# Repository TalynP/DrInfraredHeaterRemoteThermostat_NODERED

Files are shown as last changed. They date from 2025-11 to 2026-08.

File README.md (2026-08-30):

# Dr Infrared Heater Remote Thermostat

Controls a Dr Infrared Heater ([DR-996](https://drheaterusa.com/products/dr966-240-volt-hardwired-shop-garage-commercial-heater-3000-watt-6000-watt)) over a local Wi-Fi network.

This project uses a [Raspberry Pi Software Zero 2W](https://www.raspberrypi.com/products/raspberry-pi-zero-2-w/) with Raspbian GNU/Linux 12 (bookworm) with [Node-RED](https://nodered.org/) to build the logic of the thermostat.  
  
## User Pages  
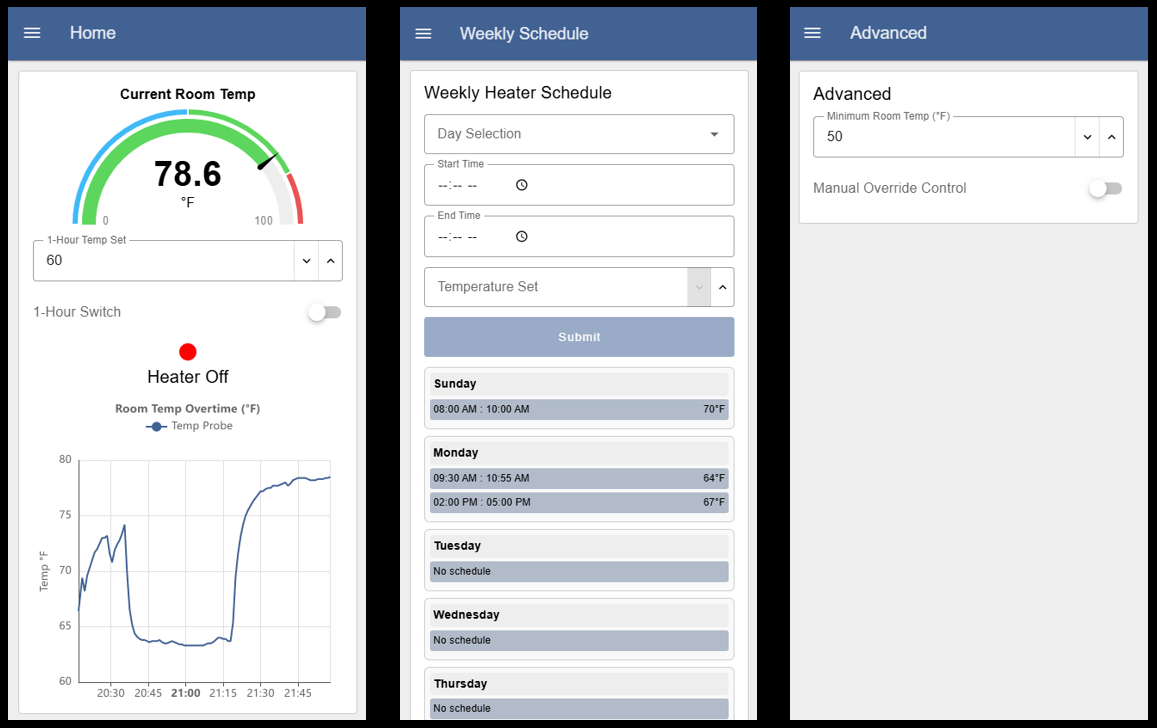
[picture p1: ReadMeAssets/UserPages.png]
Common User Pages


## Navigation
1. [Software Setup](#software-setup)
   - a. [Raspberry Pi Software Install](#raspberry-pi)
   - b. [Node-Red Install](#node-red)
   - c. [nginx and Remote Access](#nginx-and-remote-access)
   - d. [Updating](#applying-updates)
2. [Hardware](#hardware)
   - a. [BOM](#bill-of-materials-bom)
   - b. [Mounting Components](#mounting-components)
   - c. [Wiring](#wiring)
   - d. [Heater Control Panel Setup](#heater-control-panel-setup)
   - e. [Printed Circuit Board (PCB) Design](#printed-circuit-board-pcb-design)
3. [Authors Note and Future Features](#authors-note-and-future-features)
    - a. [Future Features](#future-features)

# Software Setup
## Raspberry Pi Software
Install the Raspberry Pi Software OS on to a micro SD card using the [Raspberry Pi Software Imager](https://www.raspberrypi.com/software/) software.
1. SSH into your Raspberry Pi Software
2. Update and Upgrade OS
```bash
sudo apt update && sudo apt upgrade -y
```  
3. Install [Node-RED](https://nodered.org/docs/getting-started/raspberrypi)  
```bash
bash <(curl -sL https://github.com/node-red/linux-installers/releases/latest/download/update-nodejs-and-nodered-deb)
```  
4. When it asks "Would you like to install the Pi Software-specific nodes?" select yes
5. Enable Node-RED service to run on boot  
```bash
sudo systemctl enable nodered.service
```  
6. Start Node-RED  
```bash
node-red-start
```  
7. Once you see "Started flows" type Ctrl+C
8. Enable the 1-wire interface
```bash
sudo raspi-config
```  
9. Navigate to Interface Options -> 1-Wire then select yes to enable
10. Select finish and reboot the system

## Node-RED
### RPi.GPIO Library Install
Depending on your Raspberry Pi Software OS version you may need to install/update the [RPi.GPIO](https://pypi.org/project/RPi.GPIO/) library. Command to install:
```bash
sudo apt install python3-rpi.gpio
```

Reboot your system to refresh everything once installed:
```bash
sudo reboot
```

### Access and Flows
1. Find the IP address or hostname
```bash
hostname && hostname -I
```  
2. Enter IP address or hostname at port 1880 (default Node-RED port) into a web browser  
```bash
http://<your IP or hostname>:1880
```  
3. Login to the Node-RED website  
4. Install [npm](https://www.npmjs.com/) packages from the manage pallet. Install the following:  
[flowfuse node-red-dashboard](https://flows.nodered.org/node/@flowfuse/node-red-dashboard) and [node-red-contrib-sensor-ds18b20](https://flows.nodered.org/node/node-red-contrib-sensor-ds18b20)  
5. Import the [Flows.json](./Flows.json) file ([Node_RED importing guide](https://nodered.org/docs/user-guide/editor/workspace/import-export))  
6. Deploy the new flows  
7. Enter the following in to a web browser to access the user interface
```
http://<your IP or hostname>:1880/dashboard/
```
1. The Advanced page is hidden by default from the navigation bar to access this page go to
```
http://<your IP or hostname>:1880/dashboard/advanced
```

### Flow Files
The Node-RED flows maintain two files the HeaterSchedule.json and HeaterState.log. The HeaterSchedule.json holds the time periods for the heater to maintain a temperature. Then the HeaterState.log writes when the heater turns on and off and logs the source that caused the heater to change state.  
  
An [example heater schedule](./ReadMeAssets/ExampleHeaterSchedule.json) is located in the ReadMeAssets and is described below:  
Sunday - The system will hold 70°F from 8am to 10am  
Monday - The system will hold 65°F from 9am to 11am and will hold 77°F from 2pm to 3pm  
Tuesday, Wednesday, Thursday, Friday, Saturday - No time periods

### Flow Details
For more information on how the Node-RED flows work reference [Node-REDFlowsExplained](./ReadMeAssets/Node-REDFlowsExplained.pdf) located in the ReadMeAssets.

## nginx and Remote Access
### nginx Reverse Proxy (Optional)
[nginx](https://nginx.org/) is used as a simple reverse proxy to allow a hostname such as `http://<your IP or hostname>.local` to show the Node-RED user interface (ui) dashboard website which defaults to `http://<your IP or hostname>.local:1880/dashboard/` and makes the user experience seamless. Below are the steps of how to setup nginx.  
1. Install nginx
```bash
sudo apt update
sudo apt install nginx -y
```
2. Create Node-RED site
```bash
sudo nano /etc/nginx/sites-available/nodered
```
3. Paste the contents below and change __XXXXX__ to your own hostname
```
server {
    listen 80;
    server_name XXXXX.local;

    # Redirect root to /dashboard
    location = / {
        return 301 /dashboard;
    }

    # Proxy /dashboard to Node-RED
    location /dashboard/ {
        proxy_pass http://127.0.0.1:1880/dashboard/;
        proxy_http_version 1.1;
        proxy_set_header Upgrade $http_upgrade;
        proxy_set_header Connection "upgrade";
        proxy_set_header Host $host;
        proxy_set_header X-Real-IP $remote_addr;
        proxy_set_header X-Forwarded-For $proxy_add_x_forwarded_for;
        proxy_set_header X-Forwarded-Proto $scheme;
    }
}
```
4. Once pasted and hostname added type ctrl+O then enter to save the file
5. Once saved exit by typing ctrl+X
6. Point to Node-RED site by linking
```bash
sudo ln -s /etc/nginx/sites-available/nodered /etc/nginx/sites-enabled/
```
7. Remove default nginx site from sites enabled folder (optional but recommended)
```bash
sudo rm /etc/nginx/sites-enabled/default
```
8. Test and reload nginx
```bash
sudo nginx -t
sudo systemctl reload nginx
```
9. Navigate to your `http://XXXXX.local` (server name you put in at step 3)
  
Note - nginx steps assisted in creation with OpenAI ChatGPT.

### Remote Access to the Raspberry Pi Software (Optional)
A native feature for Raspberry Pi Software's is their [Raspberry Pi Software Connect](https://www.raspberrypi.com/software/connect/) software that allows secure remote access to your Raspberry Pi Software. Below I have steps to get this working using a headless (no desktop) Raspberry Pi Software but is best to reference the official Raspberry Pi Software Connect [documentation](https://www.raspberrypi.com/documentation/services/connect.html).  

1. Install Raspberry Pi Software Connect
```bash
sudo apt install rpi-connect-lite
```
2. Turn on
```bash
rpi-connect on
```
3. Enable user lingering to automatically re-login after reboot
```bash
loginctl enable-linger
```
4. Generate hyperlink to login to Raspberry Pi Software Connect and add your Pi Software
```bash
rpi-connect signin
```
5. Use the Raspberry Pi Software Connect website to remotely connect to your Pi Software

## Applying Updates
<details>
<summary>Click to Expand</summary>

1. Acquire the latest version released of [Flows.json](./Flows.json).
2. Open your Node-Red editor.
3. Delete every existing flow (tab workspace).
4. Find the three bars in the top right and select [import](https://nodered.org/docs/user-guide/editor/workspace/import-export).
5. Select "select a file to import" and import the Flows.json file.
6. Select import to "current flow".
7. Select the red "Import" button in the bottom right.
8. If a window appears stating "Some of the nodes you are importing already exist in your workspace." select "View nodes...".
9. Under the "Configuration nodes" section select every nodes checkbox and its replace checkbox to replace all current configuration node with the new updated version.
</details>
<br>

# Hardware
## Bill of Materials (BOM)
A [bill of materials](./ReadMeAssets/DrInfraredHeaterRemoteThermostat_BOM.xlsx) has been provided and is located in the ReadMeAssets folder.

## Mounting Components
### Mounting to the Heater
The Raspberry Pi Software Zero 2W, 5v power supply and relays are mounted to the heater back mount plate then that is attached to the back of the Dr Infrared heater by two short self tapping screws. This mount was 3D printed with PETG (Polyethylene Terephthalate Glycol) the [HeaterBackMountPlate.stl](./ReadMeAssets/HeaterBackMountPlate.stl) file is located in the ReadMeAssets folder.  
  
Components mounted to heater back mount plate  
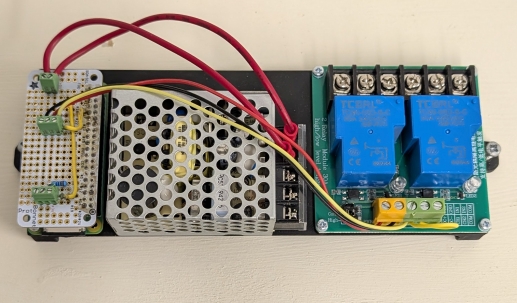
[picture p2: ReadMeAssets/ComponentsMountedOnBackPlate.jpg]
Components mounted on back plate
  

Components and back mount plate mounted to the backside of the DR-996 heater
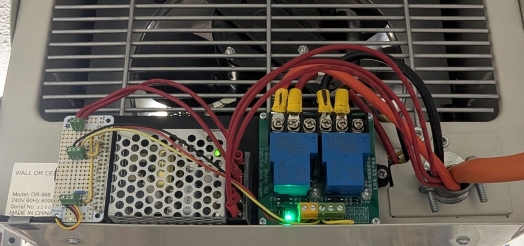
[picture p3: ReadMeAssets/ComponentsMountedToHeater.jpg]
Components mounted on back plate on backside of heater
 

### Mounting the Temperature Probe
The DS18B20 temperature probe should be at ran as far as possible from the heater and about 60 inches (152cm) from the floor. The reason to put the probe as far as possible from the heater is to allow time for the heat in the room to reach the temperature probe and evenly warm the room. The mount for the temperature probe is screwed to the wall and was 3D printed with PETG the [TemperatureProbeCase.stl](./ReadMeAssets/TemperatureProbeCase.stl) file is located in the ReadMeAssets folder. 

Temperature probe mounted to the wall  

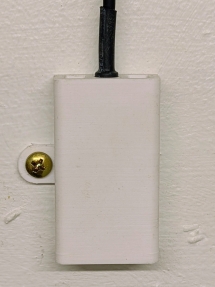
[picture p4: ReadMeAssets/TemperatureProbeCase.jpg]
TemperatureProbeCase


## Wiring
To wire the heater you should reference the [DR-966 Manual](./ReadMeAssets/DR-966Manual.pdf) in the ReadMeAssets folder or find it on the Dr Infrared Heater [website](https://drheaterusa.com/products/dr966-240-volt-hardwired-shop-garage-commercial-heater-3000-watt-6000-watt) for the DR-966. I have included a [wiring diagram](/ReadMeAssets/WiringDiagram.pdf) for how to wire the heater starting from the heavy gauge wires running from your circuit breaker panel to the heater. The wiring diagram also notes the wire gauges that I used. This is located in the ReadMeAssets folder.  

### Wiring the Temperature Probe
When wiring the temperature probe into the Raspberry Pi Software if you have already deployed the Node-RED flows you may need to go into the "Main" tab then find the red node labeled "Temp Probe" and select the sensor ID. If no ID shows up check your temperature probe wiring. Once the sensor ID is selected deploy the flows to see the live temperature displayed on the home ui page.

## Heater Control Panel Setup
The Dr Infrared Heater ([DR-996](https://drheaterusa.com/products/dr966-240-volt-hardwired-shop-garage-commercial-heater-3000-watt-6000-watt)) front control panel has a wattage power switch (red switch) and the temperature setting knob (black knob). For the fastest heating possible set the wattage power switch on the heater to the High/6KW position. Then set the temperature setting knob all the way to the high position. See the image below for how the heater’s front control panel should appear.

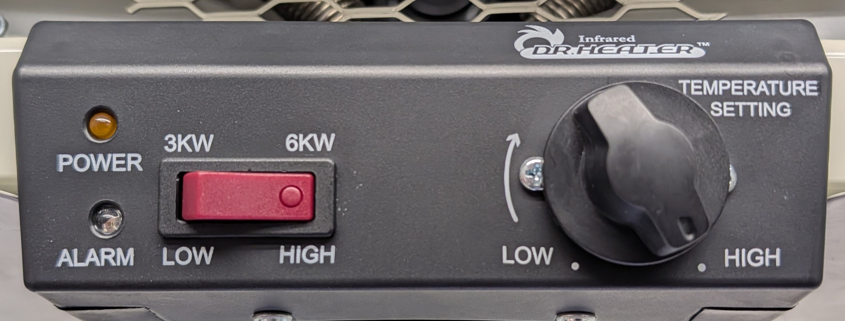
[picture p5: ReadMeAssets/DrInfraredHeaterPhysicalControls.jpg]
DrInfraredHeaterPhysicalControls


## Printed Circuit Board (PCB) Design
A custom PCB has been developed for this project reference [PCB Design Documentation](./PCB%20Design/PCBDESIGN.md) on the design and how to be able to get your own. __(08/30/2026 documentation in progress...)__

# Safety Disclaimer and Hazards
This project is great for learning about the Linux command line interface (CLI), Node-RED, 3D printing and the Internet of Things (IoT). Working with AC mains electricity, heating elements, and temperature controlled systems can be dangerous and may cause electrocution, burns, fire, property damage or violations of local electrical code if done incorrectly. __Always use safe practices for this project.__ The author assumes no responsibility, liability or fault for any damage, injury or other harm from the use of this project.

### Hazards  
- Electrical Hazards: electrocution, electrical shock, burns and fire  
- Heating Element Hazards: hot surfaces, burns and fire

### Preventing Hazards
- Check Component Ratings: Ensure components can handle the appropriate voltages and currents.
- Wire Inspection: Ensure wiring is properly insulated and no terminals are loose or exposed.
- __Hardware Shutoff__: Ensure you can easily and safely shutoff all power to the system, for example using a circuit breaker.
- __Test Test Test__: Never leave the system unattended when testing and monitor it closely.
- Follow local codes: Ensure your project complies with local electrical standards and regulations.

# Authors Note and Future Features
Finally, don't be dumb if you do not understand the dangers listed above don't do this project. I have done my best to test this system to make sure that the worst case scenario doesn't happen but cannot 100% guarantee the safety of this system.

If you would like a operating manual reach out to me via my contact information in my profile.

## Future Features
- Bash script for install.
- Celsius option for UI.
- Room heat up time prediction using excel data analysis documentation.

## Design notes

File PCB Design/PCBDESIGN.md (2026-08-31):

# Printed Circuit Board (PCB) Designs
The PCBs for this project are designed to consolidate and simplify multiple components to include the computer, power supply, and relays. A PCB allows for a robust and resistant design while simplifying connections between components.

There are two main PCB designs currently the relay board and the heater interface board. All PCBs were built by JLCPCB. If you would like the KiCad PCB files reach out to me via my contact information in my profile.
 
## Relay Board (Inactive)
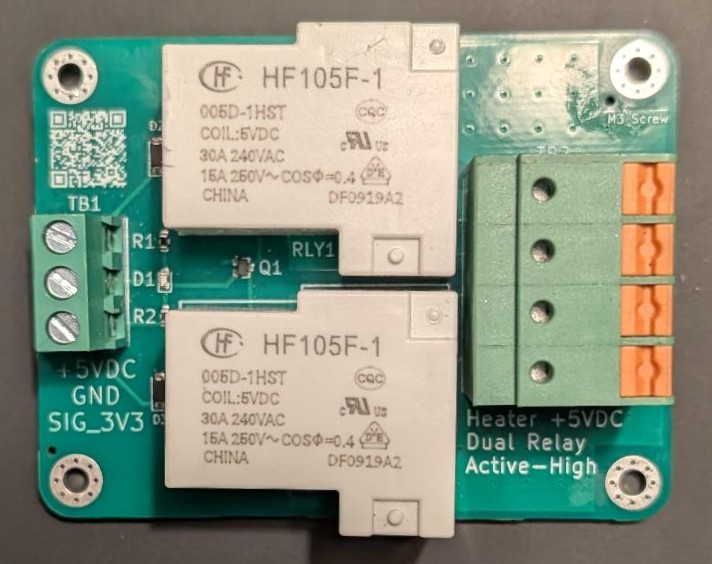
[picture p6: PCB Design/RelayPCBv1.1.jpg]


### Overview & Purpose
The relay board was built to miniaturize and simplify the original relay PCB that was bought online. The off the shelf relay PCB had 3 terminals per relay of common (COM), normally open (NO), and normally closed (NC). So the custom relay board was built to only use COM and NO terminals that made the board overall smaller. A NO connection was chose because in a de-energized state that would default the heater to being off.

### Design
The board was originally designed in EasyEDA but now is designed in KiCad because KiCad is a more commonly used program, open source, and is used with more complex designs. Overall the new custom board has a __13% smaller__ footprint.

### Additional Details
If you would like to see the specific PCB versions detailed  reference [PCB Design Overview](./PCB%20Design%20Overview.pdf).

## Heater Interface Board (Active)
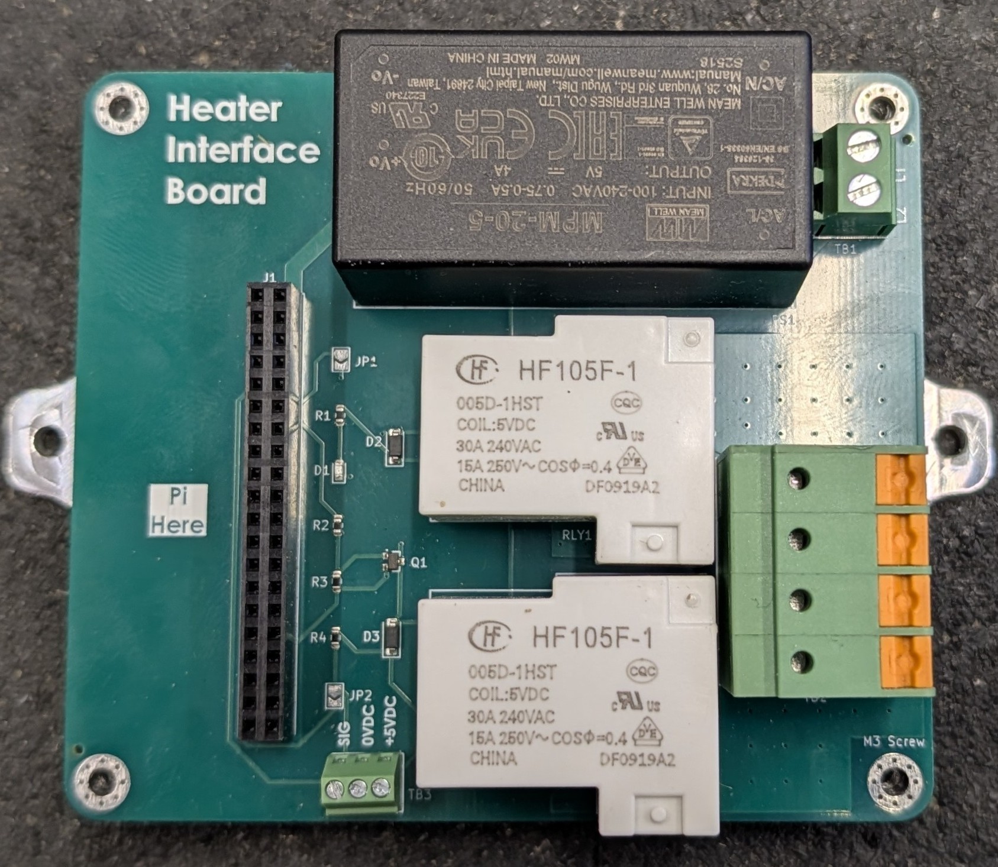
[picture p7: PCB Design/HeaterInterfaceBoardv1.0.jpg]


### Overview & Purpose
The heater interface board is the next evolution of PCB design for this project this board interfaces the computer, power supply, and relays together. An all in one design allows for a smaller footprint and less wires.

### Design
Designing this PCB has been completely done within KiCad. The main components on this board are the power supply (240VAC to 5VDC), electromechanical relays, terminal blocks, and the Raspberry Pi GPIO pin header. This boards footprint is __35% smaller__ than the original board first used in the project with the separate off the shelf relay board, power supply, and computer all being completely separate.

### Where the System is Currently


Install Date: Jan 1st, 2026

The heater has been working exceptionally well with no signs of wear or extreme heat fluctuations when the board is under load running the heater. __Additional documentation is in progress to show how to use this Heater Interface Board.__

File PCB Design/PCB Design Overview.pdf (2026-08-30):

# Heater

# PCB Design

# Iterations

## - Talyn Propst

## Table Of Contents

Why PCB Design for a Heater? | 1
Three Control Components | 1
Relay PCB | 2
Version 1.0 | 2
Version 1.1 | 3
Version 1.2 | 5
Full System PCB | 6
Version 1.0 | 6
Version 1.1 | 9

## Table of Figures

Figure 1: Three Main Components | 1
Figure 2: Relay PCB v1.0 | 2
Figure 3: Relay PCB v1.1 All Board Components | 3
Figure 4: Relay PCB v1.1 Front | 4
Figure 5: Relay PCB v1.1 Back | 4
Figure 6: Relay PCB v1.2 Front | 5
Figure 7: Full System PCB All Board Components | 7
Figure 8: Full System PCB v1.0 Front | 7
Figure 9: Full System PCB v1.0 Back | 8
Figure 10: Full System PCB v1.1 Front | 9

## Why PCB Design for a Heater?

A printed circuit board is designed to simplify and combine multiple components within a system to have a robust and resistant design. Specifically for my project I’m controlling an infrared heater I have designed an all-in-one PCB that has the circuitry to control the heater with your own local Wi-Fi network.

## Three Control Components

Within figure 1 it shows the three main components being the computer (Raspberry Pi Zero 2W), power supply and the high load relays. These are the three elements that are to be condensed down into a single PCB. Also, it will allow for an overall smaller footprint.
One way the PCB can be condensed is by simplifying the high load relays since it has more features than what’s needed by having a NO (normally open) and NC (normally closed) terminal where I only need a NO terminal.

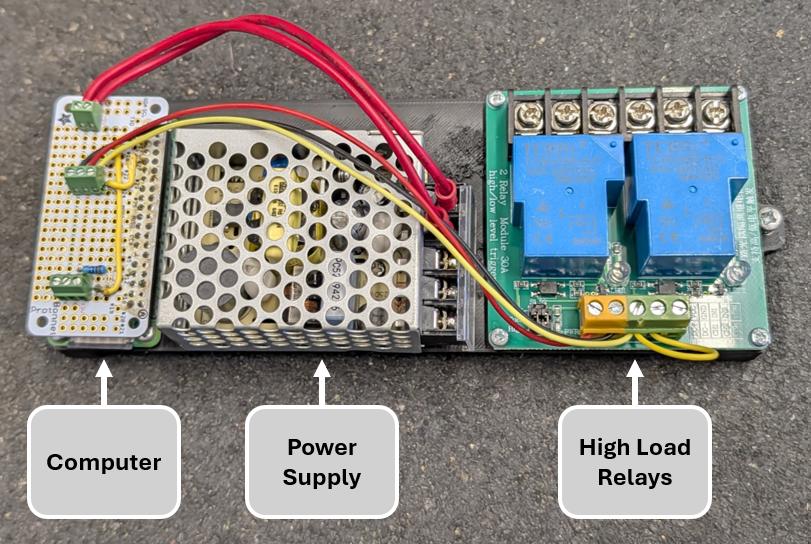
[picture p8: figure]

Figure 1: Three Main Components

## Relay PCB

The relay PCB was designed to start learning about PCB design software and to downsize the overall footprint of the relays to make the overall design smaller.

## Version 1.0

Dimensions (Length x Width): 76mm x 57.5mm Number of Layers: Two
Software: EasyEDA Online
Description:
The first relay PCB that I designed was in EasyEDA online since it was a simple PCB software that conveniently had many components, footprints and models from JLCPCB already integrated. This made ordering the PCB with components very simple since the gerber files and the JLCPCB order would all be done in one button press from the EasyEDA online software.

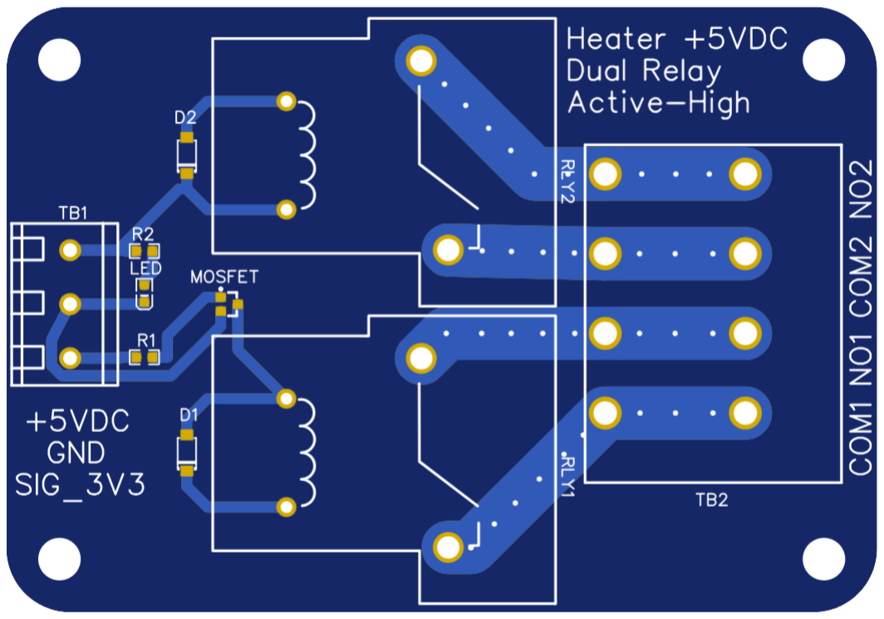
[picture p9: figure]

Figure 2: Relay PCB v1.0

## Version 1.1

Dimensions (Length x Width): 76mm x 57.5mm Number of Layers: Two
Software: Kicad 9.0
Description:
This 1.1 version relay PCB is very similar to version one except now I started using an open-source software named Kicad. This allows me to make much more complex designs seen below with nice mounting holes that are properly sized for appropriate M3 screws. Kicads learning curve was a little steep but there were many useful tutorials online. My favorite part of this new design is the QR code leading to the public GitHub repository (https://github.com/TalynP/DrInfraredHeaterRemoteThermostat_NODERED) that is the project associated with this boards use.

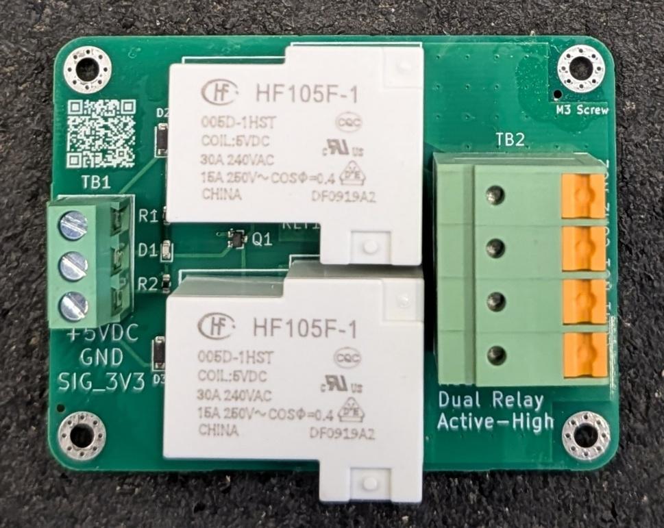
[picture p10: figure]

Figure 3: Relay PCB v1.1 All Board Components

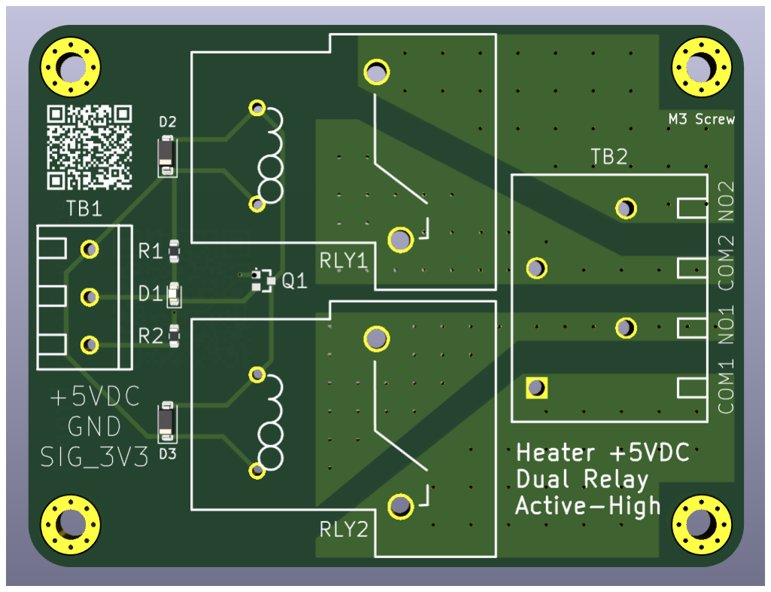
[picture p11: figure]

Figure 4: Relay PCB v1.1 Front

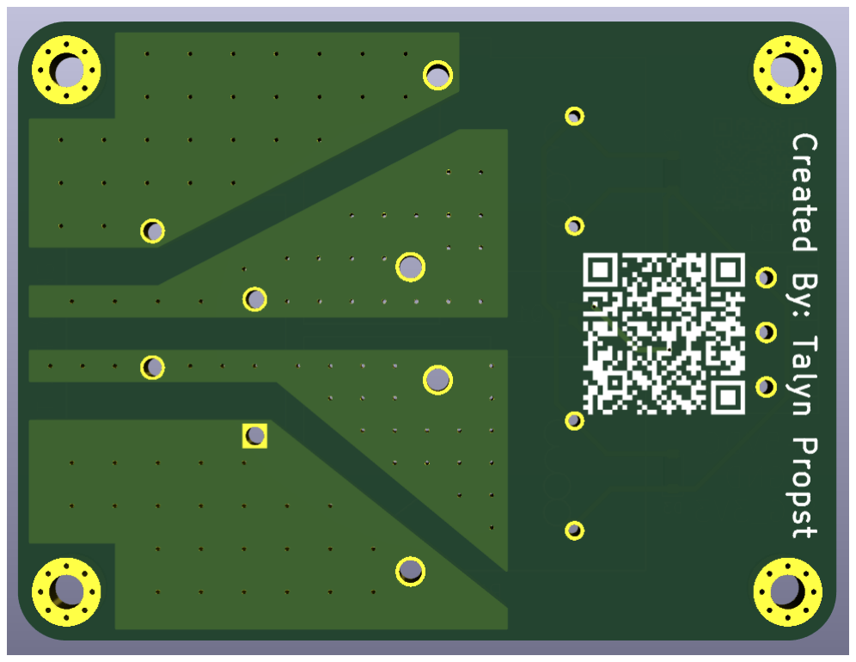
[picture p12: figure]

Figure 5: Relay PCB v1.1 Back

## Version 1.2

Dimensions (Length x Width): 76mm x 57.5mm Number of Layers: Two
Software: Kicad 9.0
Description:
Version 1.2 is identical to version 1.1 except for learning a valuable lesson when I tested version 1.1 about adding a pull-down gate resistor. A pull-down gate resistor was needed because when I connected the board to power with +5VDC and GND (0VDC) then the 3.3v signal was not connected and the N-type MOSFET would be in a floating state flickering the relays partially on and off very fast sounding like a taser. Though when the 3.3v signal was connected this stopped as the MOSFET gate now had a known reference voltage.
While not a major issue the board can operate but it was addressed because it was unsatisfactory and unprofessional when hooking up the board with power and ground first making the relays sound like a taser also, this could have damaged a load if connected to the output of the relays. Within figure 6 you can see there is an additional resistor (R3) for the MOSFET gate pull down.

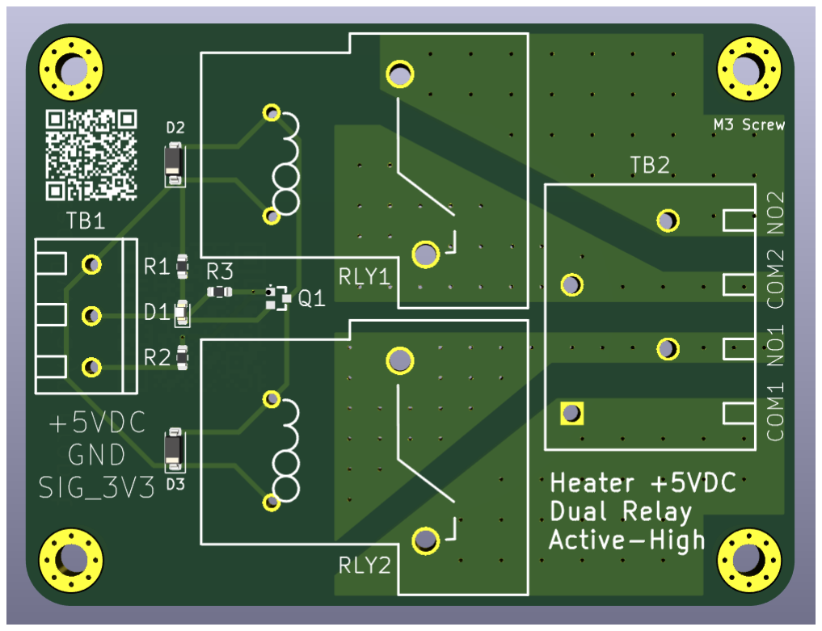
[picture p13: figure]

Figure 6: Relay PCB v1.2 Front

## Full System PCB

A full system PCB design was started shortly after version 1.1 of the PCB relay after it was tested and worked showing my calculations were correct. The goal of this all-in-one PCB is to have a smaller footprint, less hookup wires and robust circuitry.

## Version 1.0

Dimensions (Length x Width): 100mm x 88mm Number of Layers: Four
Software: Kicad 9.0
Description:
Version 1.0 of the full system PCB has a major focus on high voltage AC isolation from low voltage DC to prevent interference. Originally, I wanted to design a power supply but upon reading a book the author recommended if someone sells what you need just buy their product and avoid the complex calculations of switch mode power supplies. Glad I did because the Meanwell MPM-20-5 has worked great for converting +240VAC to +5VDC to power the relays and computer on the full system PCB. The relays on the board are the same design as from the relay PCB one change is the removal of solder mask on the bottom layer seen in figure 9. This is to enhance cooling of the heavy amperage load the relays and terminal block pass between each other. One other major change to this board is that its four layers and 1oz copper weight allowing for efficient energy transfer and heat dissipation of the high amperage load.

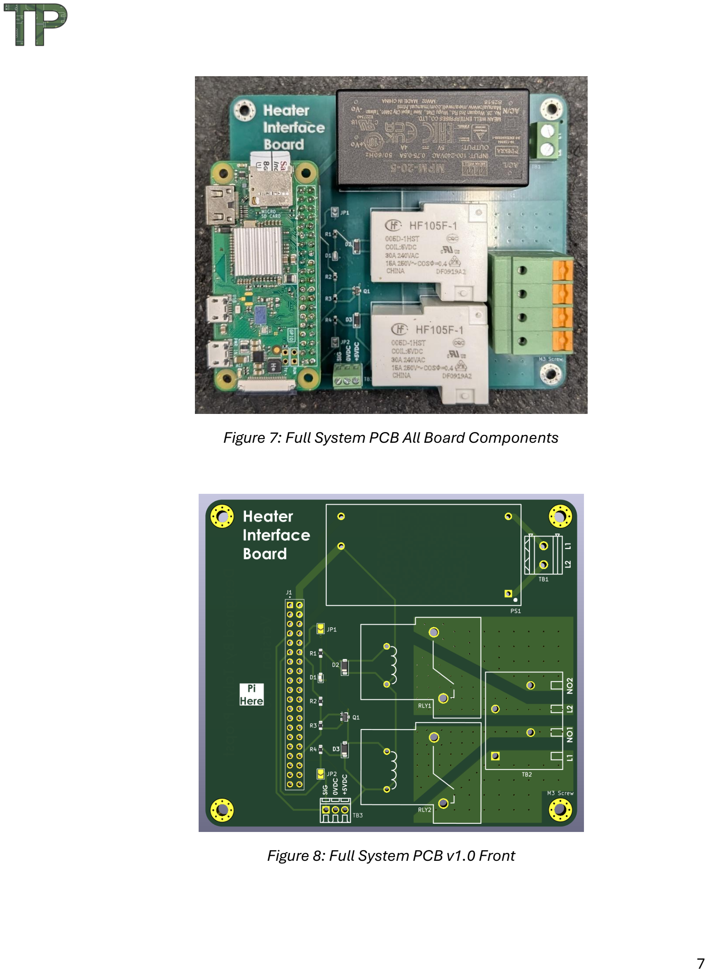
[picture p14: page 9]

Figure 7: Full System PCB All Board Components

Figure 8: Full System PCB v1.0 Front

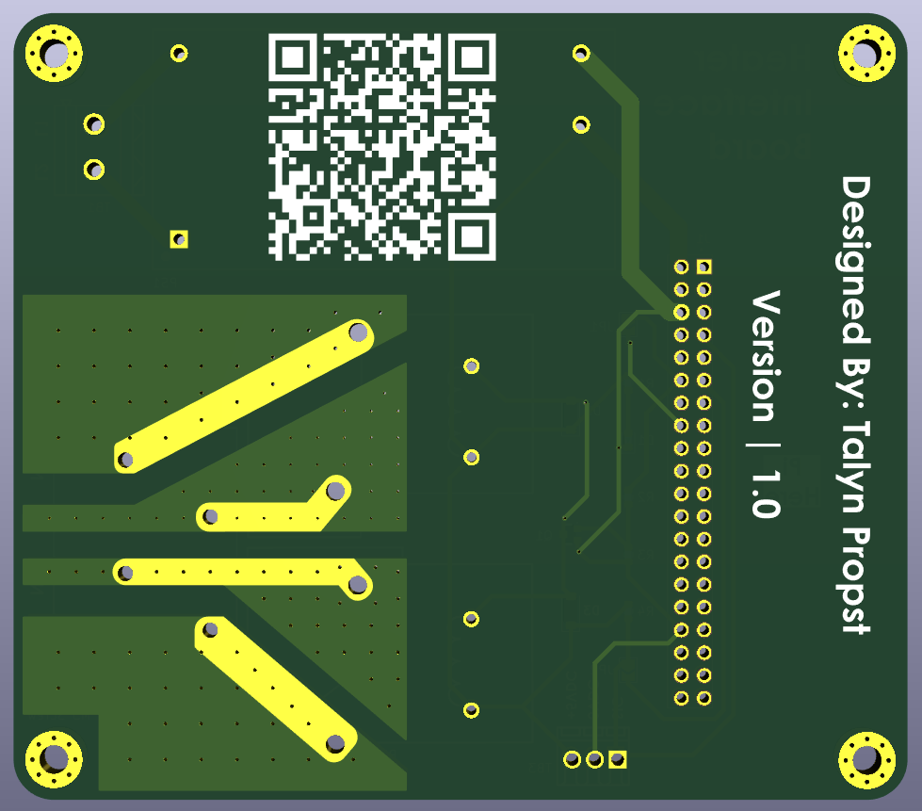
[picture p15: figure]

Figure 9: Full System PCB v1.0 Back

## Version 1.1

Dimensions (Length x Width): 100mm x 88mm Number of Layers: Four
Software: Kicad 9.0
Description:
Version 1.1 comes with new trace routing and two more jumper pads. All four jumper pads are used for connecting and disconnecting a general-purpose input output (GPIO) pin to be able to use a backup GPIO pin in case of a failure. The problem fixed of the trace routing had nothing to do with the actual schematic is happened that for the backup relay pin that its signal also ran through the original pin and if that happened to fail and it was permanently stuck in a low or high state the backup pin would have not been able to change the relay state due to its routing.

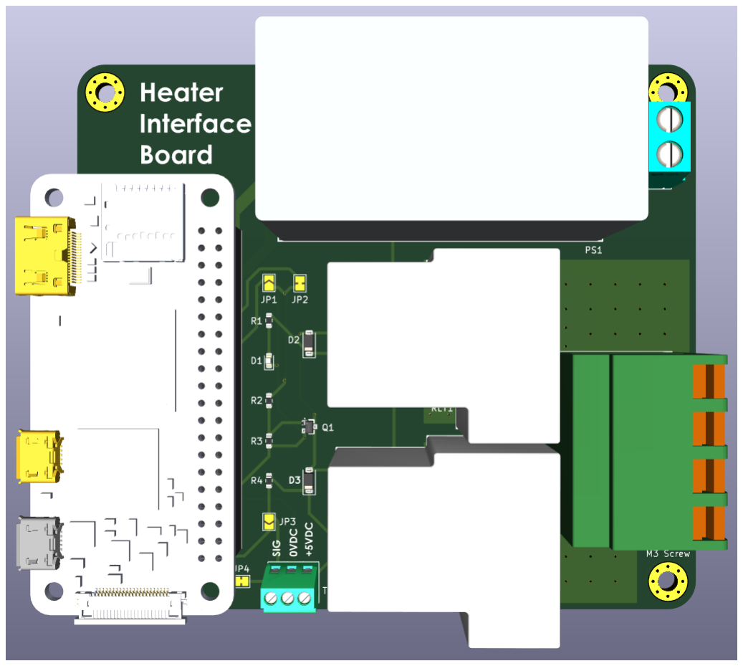
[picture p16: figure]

Figure 10: Full System PCB v1.1 Front

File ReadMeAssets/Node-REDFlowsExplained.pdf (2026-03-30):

# Dr Infrared Heater Remote Thermostat

# Node-RED Flows Explained

## Table Of Contents

## Basics

Node-RED has multiple tabs in this case there are Main, Heater Logic, Advanced, and Debug. Each tab has flows. The flow is multiple nodes connected via wires. Node-RED has three levels of context node, flow and global. Node context is where only a node knows that information for itself. Flow context is where information can be seen by all connected nodes or in the same tab. Global context is where information can be seen by any node. Node names that are highlighted blue have default values that you can easily change such as default minimum room temperature and more. Node-RED uses messages (msg) to pass information between nodes via the wires. The most common message is msg.payload.

## Main Flows

## Setting Default State

Overview – This flow runs 100ms after Node-RED boots and initializes variable default values and logs status.
Node Details
- Initialize State
- Injects at 100ms after boot to start flow.
- Filename and Path
- Sets filename path for HeaterSchedule.json.
- Init msg
- Changes msg.payload to false.
- 1 Hour and Manual Switches Init Out (White arrow block)
- Connects to “1 Hour Switch Init In” and “Manual Override Switch Init In”.
- 1 Hour and Min Room Temp Init Out (White arrow block)
- Connects to “1-Hour Temp Set In” and “Min Room Temp In”.
- Read In Heater Schedule First
- Reads in HeaterSchedule.json file if it exists.

- Parse Heater Schedule
- Parses heater schedule from JSON (JavaScript object notation) to JavaScript object.
- Set Global Context
- Set variables heaterSchedule, currentHeaterPinState, manualControlState, oneHourSwitchState and tempProbeError to default values.
- Signature
- Sets msg.signature to “init” letting the following node know where the message came from.
- Schedule init out (White arrow block)
- Connects to “Init in 1” and “Init in 2” nodes.
- Change msg Contents
- Change msg.payload to false.
- Log Initialization
- Creates log message indicating that the system has booted.
- Log Initialization Out (White arrow block)
- Connects to “Write to Heater Log In” node to write to HeaterState.log.
- Heater Relay Switch Default State
- Sets relay pin state low when control system boots.

## 1-Hour Temp Set

Overview – This flow sets the default valve of the 1-Hour Temp Set and updates a global variable.
Node Details
- 1-Hour Temp Set Init In (White arrow block)
- Gets message from “1 Hour and Min Room Temp Init Out” and routes to next node.
- Default Value
- Holds integer for default value of 1-Hour Temp Set which is 60°F. You can change this by selecting the node and changing the value of 60 to your desired temperature then deploy your change. I would not go higher than what you are comfortable heating your room too or make the heater run too often.
- 1-Hour Temp Set
- Numeric user interface (ui) node that allows the user to change this value from the ui. The default range is 0°F to 80°F to change this select the node then deploy your change.
- Set Global Var
- Sets global variable “oneHourTempSet” when changed from ui.
- UI Change
- Detects a refresh or page change happens to make sure that the oneHourTempSet value displayed is accurate.
- Get oneHourTempSet Global
- Get the stored value for the oneHourTempSet.
- 250ms Delay
- Delays message by 250ms.

## 1-Hour Switch

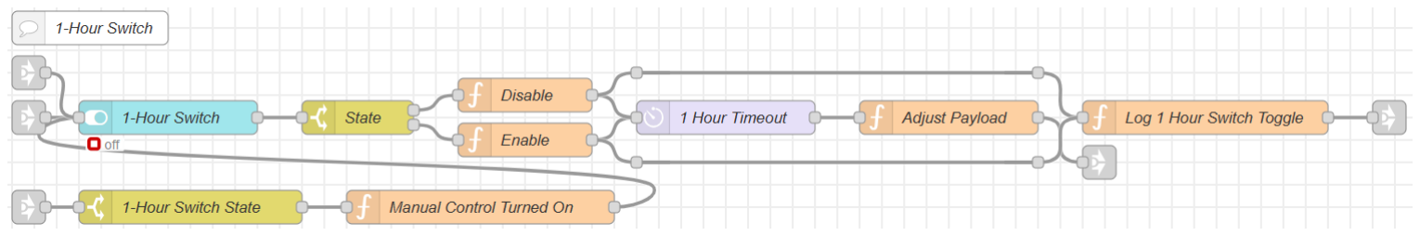
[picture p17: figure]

Overview – This flow monitors the state of the 1-Hour Switch and will direct the proper information to the heater logic to turn the heater on or off. This also automatically turns the 1-Hour switch off after an hour.
Node Details
- 1 Hour Switch Init In (White arrow block)
- Ensures switch defaults to off on boot and Node-Red redeploy.
- 1-Hour Switch Control In (White arrow block)
- Receives message from 1-Hour Switch Control Out.
- 1-Hour Switch
- UI switch for 1-hour switch.
- State
- Check if 1-hour switch has been turned on or off.

- Disable
- Sets “oneHourSwitchState” global variable to false, msg.payload to false, and msg.reset to blank to reset the 1-hour timer countdown to shutoff the heater.
- Enable
- Sets “oneHourSwitchState” global variable to true and msg.payload to true.
- 1 Hour Timeout
- Tracks a 1-hour timer to shut off switch after an hour.
- Adjust Payload
- Sets msg.payload to false to turn the 1-hour heater switch off after an hour.
- Log 1 Hour Switch Toggle
- Creates log message when the 1-hour switch is turned on or off.
- 1-Hour Switch Control Out (White arrow block)
- Passes 1-hour timeout shut off message to “1-Hour Switch Control In” to update ui.
- Log 1 Hour Switch Out (White arrow block)
- Sends log message to “Write To Heater Log In” to write to HeaterState.log.
- 1-Hour Switch Control Turn Off In (White arrow block)
- Message in from Manual Override Control to turn off 1 hour switch
- 1-Hour Switch State
- Check if 1-hour switch is on, if so then the message will go through to shut it off when the manual override control is turned on.
- Manual Control Turned On
- Sets msg.payload to false and msg.manualControlTurnOff to true.

## Write Messages to Log File

Overview – This flow writes out all logs for the HeaterState.log file. Node Details

- Write To Heater Log In (White arrow block)
- Routes all HeaterState.log messages to be written in next node.

- Filename and Path
- Set filename path for HeaterState.log.
- Write Heater Log
- Writes by appending to HeaterState.log.

## Query, Check, Update and Display Room Temp

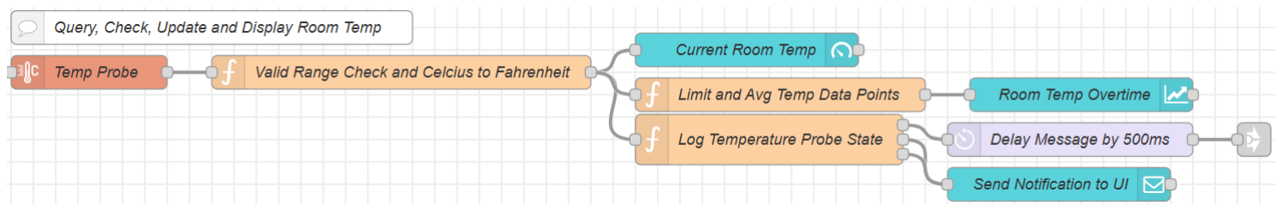
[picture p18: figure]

Overview – This flow gets the temperature probe reading then verifies its within the data sheets range of -55C to 125C. Once that is good it will convert the temperature from Celsius to Fahrenheit and shows this on the temperature gauge and a graph. With this monitoring the temperature range and temperature probe connection or disconnection, if either happens a notification is sent to the UI.
Node Details
- Temp Probe
- Get temperature from DS18B20 temperature sensor.
- Valid Range Check and Celcius to Fahrenheit
- This node checks that the temperature probe is connected and will send the proper errors if not. Then also checks that the temperature reading is within its rated range of -55C to 125C and will send the proper errors if not. If either of these errors are detected the heater will be shutoff. Note with detecting when the probe disconnects is it can take an average of three minutes for it to detect that the temperature probe has disconnected this is due to the 1 wire bus taking time to update on the Raspberry Pi.
- Current Room Temp
- UI gauge showing real time room temperature.
- Limit and Avg Temp Data Points
- Averages the temperature every minute to send to the Room Temp Overtime node.
- Room Temp Overtime
- UI graph showing room temp over the last 12 hours you can change this in the node by changing the X-Axis Limit time from 12 hours to what you desire.

- Log Temperature Probe State
- Logs if temperature probe becomes connected, disconnected, out of range or back within range. This will send the downstream message to notify the UI of any issues such as disconnection or out of range.
- Delay Message 500ms
- Message waits half a second to continue through.
- Send Notification to UI
- Displays notification to UI.
- Log Temperature Sensor State Out (White arrow block)
- Route log message to “Write To Heater Log In” to write to HeaterState.log.

## Check for Valid Schedule Inputs

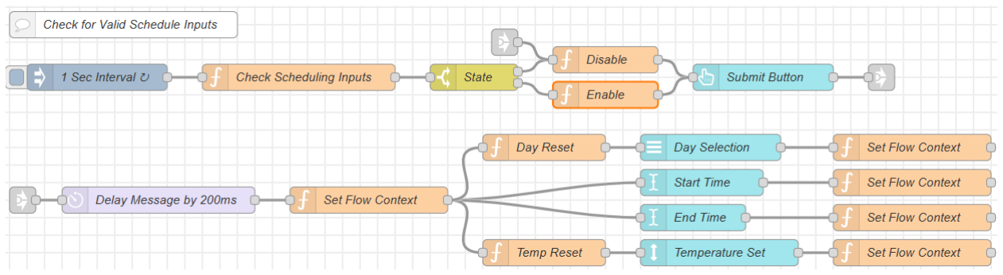
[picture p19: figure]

Overview – This flow looks for the user adding a new time period to the schedule and will check for the correct conditions to allow the information to be submitted.
Node Details
- 1 Sec Interval
- Injects message every second to check for valid period information to be potentially added.
- Checking Scheduling Inputs
- Checks day selection, start time, end time and temperature for valid values to enable submit button.
- State
- Check if ready to enable submit button.
- Schedule init in 2 (White arrow block)
- Ensures the submit button is disabled when system boots.
- Disable
- Sets msg.enabled to false making button disabled.

- Enable
- Sets msg.enabled to true making button enabled.
- Submit Button
- UI button that when pressed starts the process to add the time period and temperature to the HeaterSchedule.json file.
- Update Schedule Out (White arrow block)
- Routes messages to “Update Schedule In 1” and “Update Schedule In 2”.
- Update Schedule In 1 (White arrow block)
- Receives message from “Update Schedule Out”.
- Delay Message by 200ms
- Delays message to not clear inputs instantly.
- Set Flow Context
- Sets day selection, start time, end time and temperature to null effectively resetting the values and msg.payload to empty.
- Day Reset
- Sets msg.payload to an empty array and msg.ui_update to null to reset input box.
- Day Selection
- UI dropdown to select day.
- Start Time
- UI text input to set start time of period.
- End Time
- UI text input to set end time of period.
- Temp Reset
- Sets msg.payload to an empty array and msg.ui_update to null to reset input box.
- Temperature Set
- UI number input to set temperature for period.
- Set Flow Context (x4)
- Sets appropriate flow variables for day selection, start time, end time and temperature.

## Update and Display Schedule and Changes

Overview – This flow works with the prior flow to add the period to the schedule. Node Details

- Update Schedule In 2 (White arrow block)
- Receives message from “Update Schedule Out”.
- Change msg Name
- Assigns msg.newTime with the current payload and adds msg.filename for HeaterSchedule.json path.
- Read In Heater Schedule
- Reads in HeaterSchedule.json file.
- Parse Heater Schedule
- Parses heater schedule from JSON to JavaScript object.
- Add New Time
- Adds new time to JavaScript object.
- Schedule init in 1 (White arrow block)
- Receives message from “Init out” to show the week schedule in the ui.
- Show Week Schedule
- UI template node is used to build heater schedule display and to delete schedules.
- From Who
- Blocks messages from going farther if from initialization.
- Set Flow Context
- Sets global heaterSchedule to new updated schedule.
- Parse Heater Schedule
- Converts JavaScript object back to JSON.
- Filename and Path
- Sets filename path for HeaterSchedule.json.
- Update Heater Schedule
- Writes new updated heater schedule to HeaterSchedule.json.

## Creates Empty Heater Schedule File If Missing

Overview – This flow ensures that if there is no HeaterSchedule.json it will write a new a blank template.
Node Details
- Write New Empty Schedule File
- Node will catch errors when trying to read HeaterSchedule.json file if it doesn’t exist.
- Empty Weekly Schedule Template
- Empty JavaScript template object for schedule and includes the filename and path to write to.
- Write New Schedule File
- Write the new HeaterSchedule.json file.
- Check For File Missing Error
- Used to output debug message if this flow was activated.

## Delete Contents of Log Weekly

Overview – This flow will overwrite the HeaterState.log file every week by default is set to 5am on Sunday morning.
Node Details
- Time to Overwrite
- Send a message at the time to overwrite the HeaterState.log file to clear. The default time can be changed by selecting this node then deploying the new change.
- Filename and Path
- Set the filename path for HeaterState.log.
- Overwrite HeaterState.log
- Overwrites the file to make it empty.

## Heater Logic Flows

Overview – This flow is the actual logic to determine when to change the heater state (GPIO 18 pin).
Node Details
- 1 Sec Interval
- After a two second delay it injects a message every second to check heater logic.
- Valid Temp Input
- Checks that tempProbeError global is valid by ensuring it’s not true or undefined.
- Manual Override State
- Checks that the manual override state is on or off.
- Turn Off When Sensor Error
- Turns off heater when no temperature probe is detected or out of temperature range.
- Get Manual Control State
- Grabs the manualControlState global value.
- 1-Hour Switch
- Checks that the 1-Hour Switch is on or off.
- Get One Hour Temp Set
- Retrieves the global oneHourTempSet.
- Get Day & Time
- Gets the current day and time to make msg.day, msg.hour and msg.min.
- Check Daily Schedule Time
- Iterates through global heaterSchedule object to find if any periods should be running currently.
- Thermostat Control
- Accounts for several global variables and msgs to find the highest setpoint and may change the state of the heater depending on the room temperature.
- Filter
- Blocks most messages unless they have the msg.confirmed message being true.

- State Changed
- Checks for when msg.payload changes to record log to HeaterState.log.
- Heater Relay Switch
- GPIO 18 pin that is turned on or off by thermostat control node.
- LED Indicator
- Indicates heater state by displaying “Heater On” and turning green then off by displaying “Heater Off” and turning red.
- Log Heater Source While On
- Creates log message to write to HeaterState.log with message saying new heater source and that the heater is still on.
- Log Heater State
- Creates log message to write to HeaterState.log.
- Log Schedule Control Out (White arrow block)
- Routes log message to “Write To Heater Log In” to write to HeaterState.log.

## Advanced Flows

## Minimum Room Temp

Overview – This flow sets the default valve of the Minimum Room Temp and updates a global variable.
Node Details
- Min Room Temp In (White arrow block)
- Gets message from “Min Room Temp Out” and routes to next node
- Default Value
- Holds integer for default value for minimum room temp which is 50°F. You can change this by selecting the node and change the value of 50 to your desired temperature then deploy the change. I would not go higher than what you are comfortable heating your room too or make the heater run too often.

- Minimum Room Temp
- Numeric user interface (ui) node that allows the user to change this value from the ui. The default range is 0°F to 80°F to change this select the node and change the values then deploy your change.
- Set Global Var
- Sets global variable “minimumRoomTemp” when changed from ui.
- UI Change
- Detects a refresh or page change happens to make sure that the oneHourTempSet value displayed is accurate.
- Get minimumRoomTemp Global
- Get the stored value for the minimumRoomTemp.
- 250ms Delay
- Delays message by 250ms.

## Manual Override Control

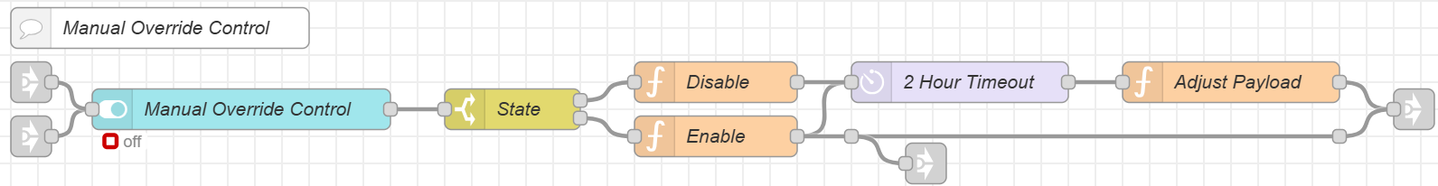
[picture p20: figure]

Overview – This flow controls the manual override control switch to forcefully turn the heater on nonstop for two hours before automatically turning off.
Node Details
- Manual Override Switch Init In (White arrow block)
- Ensures switch defaults to off on boot and Node-Red redeploy.
- Heater Switch Control In (White arrow block)
- Receives message from Heater Switch Control Out.
- Manual Override Control
- UI switch for manual override control.
- State
- Check if manual override control switch has been turned on or off.
- Disable
- Sets “manualControlState” global variable to false, “currentHeaterPinState“ global variable to false, msg.payload to false, and msg.reset to blank to reset the 2-hour timer countdown to shutoff the heater.

- Enable
- Sets “manualControlState” global variable to true, “currentHeaterPinState” global variable to true and msg.payload to true.
- 2 Hour Timeout
- Tracks a 2-hour timer to shut off manual override control switch and heater after two hours.
- 1-Hour Switch Control Turn Off Out (White arrow block)
- Sends message to “1-Hour Switch Control Turn Off In” to potentially turn off the 1-hour switch if it was on.
- Adjust Payload
- Sets msg.payload to false to turn the manual override control switch and heater off.
- Heater Switch Control Out (White arrow block)
- Passes 2-hour timeout shut off message to “Heater Switch Control In” to update ui.

## Debug Flows

## currentHeaterPinState

Overview – This flow allows you to poll the value of currentHeaterPinState at any time and read in the debug window in Node-RED.
Node Details
- Inject
- Select to start message injection.
- currentHeaterPinState
- Get the current value of currentHeaterPinState.
- currentHeaterPinState (green)
- Displays value in debug window.

## heaterSchedule

Overview – This flow allows you to poll the value of heaterSchedule at any time and read in the debug window in Node-RED.
Node Details
- Inject
- Select to start message injection.
- heaterSchedule
- Get the current value of heaterSchedule.
- heaterSchedule (green)
- Displays value in debug window.

## lastHeaterSchedule

Overview – This flow allows you to poll the value of lastHeaterSource at any time and read in the debug window in Node-RED.
Node Details
- Inject
- Select to start message injection.
- lastHeaterSource
- Get the current value of lastHeaterSource.
- lastHeaterSource (green)
- Displays value in debug window.

## manualControlState

Overview – This flow allows you to poll the value of manualControlState at any time and read in the debug window in Node-RED.
Node Details
- Inject
- Select to start message injection.
- manualControlState
- Get the current value of manualControlState.
- manualControlState (green)
- Displays value in debug window.

## minimumRoomTemp

Overview – This flow allows you to poll the value of minimumRoomTemp at any time and read in the debug window in Node-RED.
Node Details
- Inject
- Select to start message injection.
- minimumRoomTemp
- Get the current value of minimumRoomTemp.
- minimumRoomTemp (green)
- Displays value in debug window.

## oneHourSwitchState

Overview – This flow allows you to poll the value of oneHourSwitchState at any time and read in the debug window in Node-RED.
Node Details
- Inject
- Select to start message injection.
- oneHourSwitchState
- Get the current value of oneHourSwitchState.
- oneHourSwitchState (green)
- Displays value in debug window.

## oneHourTempSet

Overview – This flow allows you to poll the value of oneHourTempSet at any time and read in the debug window in Node-RED.
Node Details
- Inject
- Select to start message injection.
- oneHourTempSet
- Get the current value of oneHourTempSet.
- oneHourTempSet (green)
- Displays value in debug window.

## roomTemp

Overview – This flow allows you to poll the value of roomTemp at any time and read in the debug window in Node-RED.
Node Details
- Inject
- Select to start message injection.
- roomTemp
- Get the current value of roomTemp.
- roomTemp
- Displays value in debug window.

## tempProbeError

Overview – This flow allows you to poll the value of tempProbeError at any time and read in the debug window in Node-RED.
Node Details
- Inject
- Select to start message injection.
- tempProbeError
- Get the current value of tempProbeError.
- tempProbeError
- Displays value in debug window.

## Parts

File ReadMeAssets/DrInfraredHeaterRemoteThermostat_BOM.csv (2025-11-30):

Description | Part Number | Distributor/Link | Quantity | Price | Total
Dr Infrared Heater DR-966 | DR-966 | Dr.Heater | 1 | $200.00 | $200.00
Raspberry Pi Zero 2W | 2648-SC0721-ND | Digikey | 1 | $18.00 | $18.00
Samsung PRO Endurance 128GB MicroSD Card | B09WB1857W | Amazon | 1 | $22.99 | $22.99
Raspberry Pi Heat Sink | 1528-1698-ND | Digikey | 1 | $0.95 | $0.95
Raspberry Pi Zero Proto Bonnet Board | 1528-2041-ND | Digikey | 1 | $4.50 | $4.50
Waterproof 1-Wire DS18B20 Digital temperature sensor | 1528-1592-ND | Digikey | 1 | $9.95 | $9.95
Two Position Terminal Block | 277-1273-ND | Digikey | 2 | $1.93 | $3.86
Three Position Terminal Block | 277-1274-ND | Digikey | 2 | $2.77 | $5.54
Wago Wire Connector | 2946-221-613-ND | Digikey | 3 | $1.26 | $3.78
120-240vac to 5vdc power supply | 1866-4133-ND | Digikey | 1 | $8.60 | $8.60
Dual Channel 5vdc control 240vac 30 Amp Relay Board | B07DSXWPC1 | Amazon | 1 | $10.99 | $10.99
Power Supply Phillips Screw (M3 x 6mm) | 92005A116 | McMaster-Carr | 1 | $4.48 | $4.48
Raspberry Pi and Relay Board Phillips Screw (M3 x 0.5mm) | 92005A052 | McMaster-Carr | 1 | $6.87 | $6.87
AWG 10 stranded 600v black wire 25ft | 8054T29-9154T211 | McMaster-Carr | 1 | $36.34 | $36.34
AWG 10 stranded 600v green wire 25ft | 8054T29-9154T233 | McMaster-Carr | 1 | $36.34 | $36.34
AWG 16 stranded 600v black wire 25ft | 8054T26-8054T866 | McMaster-Carr | 1 | $9.37 | $9.37
AWG 16 stranded 600v green wire 25ft | 8054T26-8054T02 | McMaster-Carr | 1 | $9.37 | $9.37
AWG 18 stranded 600v black wire 25ft | 8054T25-8054T805 | McMaster-Carr | 1 | $6.48 | $6.48
AWG 18 stranded 600v red wire 25ft | 8054T25-8054T849 | McMaster-Carr | 1 | $6.48 | $6.48
AWG 18 stranded 600v yellow wire 25ft | 8054T25-8054T861 | McMaster-Carr | 1 | $6.48 | $6.48
AWG 20 solid 300v yellow wire 25ft | 8251T3-8251T621 | McMaster-Carr | 1 | $5.28 | $5.28
Spade Connector Kit 330pcs | B0C56Y6D2W | Amazon | 1 | $9.39 | $9.39
3D printed Heater Back Mount Plate |  |  | 1 |  | $0.00
Back mount plate screws (#6 x 1/2-Inch Phillips Pan-Head screw) | 2337250 | Menards | 1 | $1.28 | $1.28
3D printed temperature probe case |  |  | 1 |  | $0.00
Probe case screws (#8 X 3/4-Inch Phillips Pan-Head screw) | 2010225 | Menards | 1 | $1.19 | $1.19
Grand Total: |  |  |  |  | $426.04

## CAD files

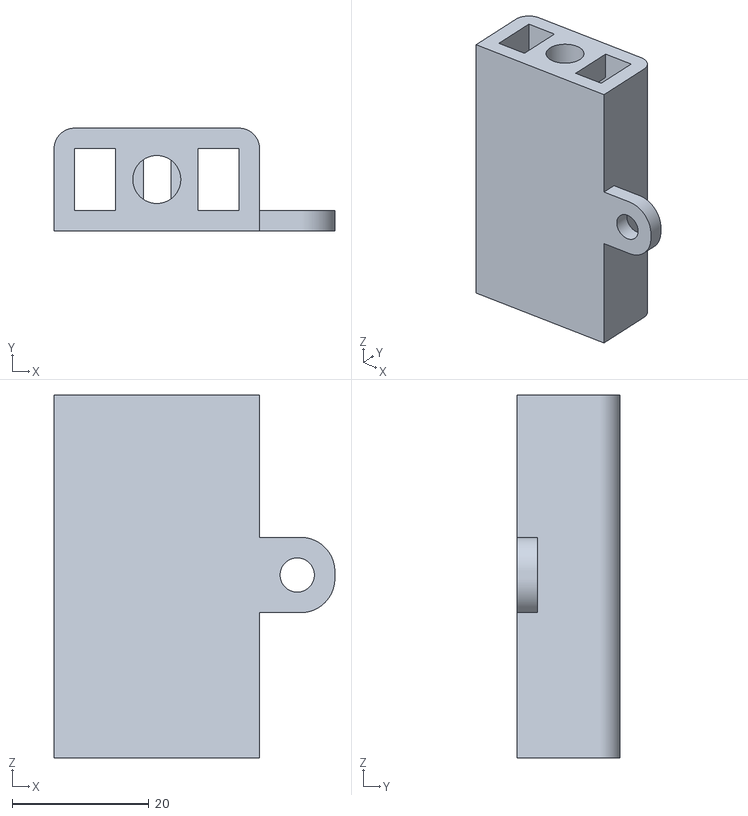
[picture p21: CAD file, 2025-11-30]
ReadMeAssets/TemperatureProbeCase.stl
41.0 x 15.0 x 53.0

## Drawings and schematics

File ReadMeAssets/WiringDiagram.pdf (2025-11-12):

-+

### Relay

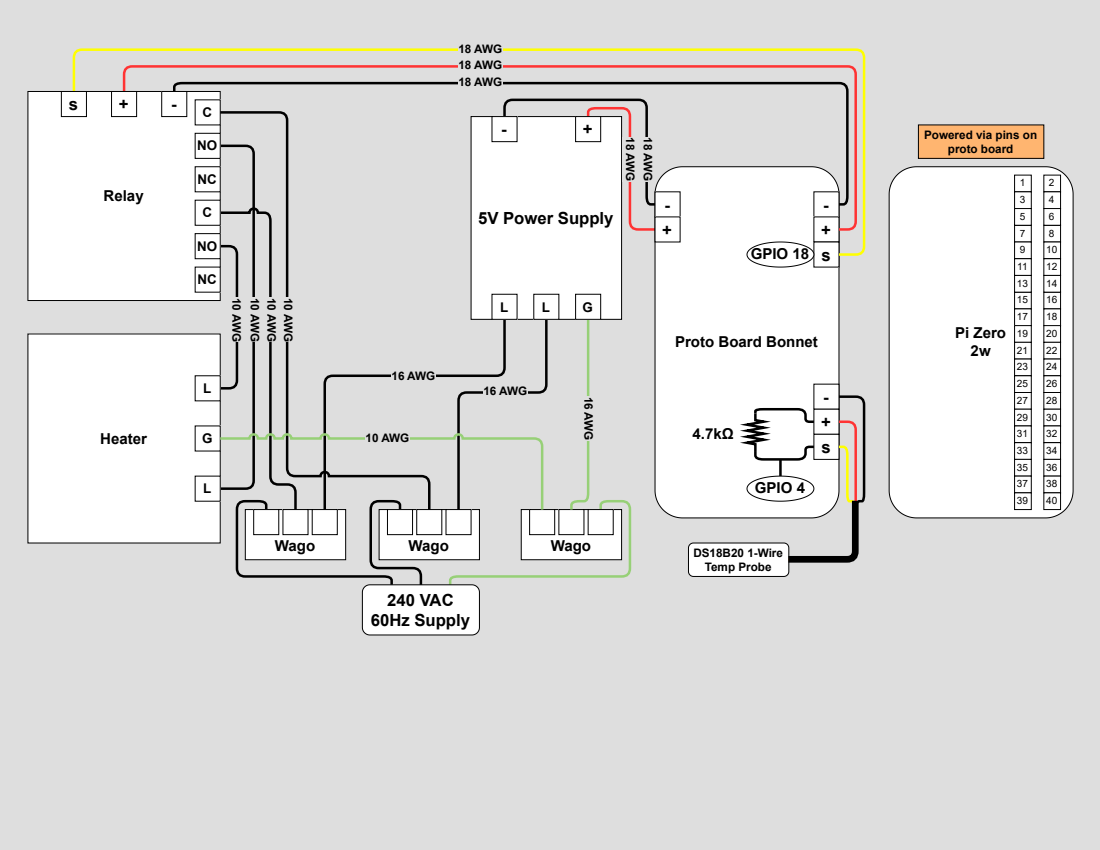
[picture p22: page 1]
240 VAC 60Hz Supply; Wago; NCC; Heater; GLL; Pi Zero 2w; 10 AWG; 5V Power Supply L; AWG; 16 AWG; 18 AWG; GPIO 4; GPIO 18

Powered via pins on
proto board

Proto Board Bonnet

DS18B20 1-Wire Temp Probe

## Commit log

2025-08-17 Trying new formatiing for ReadMe
    [Dr-Infrared-Heater-Remote-Thermostat BOM.xlsx]
2025-08-17 BOM items added and more formatting to the ReadMe.
    [Dr-Infrared-Heater-Remote-Thermostat BOM.xlsx]
2025-08-17 Added BOM Link
2025-11-01 Fixed bracket
2025-11-01 New ReadMe files added with new ReadMe contents like the Hardware Section.
    [DrInfraredHeaterRemoteThermostat_BOM.xlsx, TemperatureProbeCase.stl]
2025-11-01 Old BOM removed
    [Dr-Infrared-Heater-Remote-Thermostat BOM.xlsx]
2025-11-01 UPdated ReadMe with wiring section. Added new ReadMeAssets files - DR966Manual, updated wiring diagram, and updated BOM.
    [DrInfraredHeaterRemoteThermostat_BOM.xlsx]
2025-11-06 Updated readme style and BOM.
    [DrInfraredHeaterRemoteThermostat_BOM.xlsx]
2025-11-11 Added Flows.json file.
2025-11-12 Updated BOM with screws. Added new image to readMe of temperature probe case. Added temp probe case image.
    [DrInfraredHeaterRemoteThermostat_BOM.xlsx]
2025-11-12 Updated ReadMe instructions software section. Updated wiring diagram.
2025-11-12 Swapped GPIO on wiring diagram to be accurate.
2025-11-13 Added Back Mount Plate images.
2025-11-13 BOM updated with AWG 20 solid core.
    [DrInfraredHeaterRemoteThermostat_BOM.xlsx]
2025-11-30 Added new and improved STL's for HeaterBackMountPlate and TemperatureProbeCase.
    [TemperatureProbeCase.stl]
2025-11-30 Added new updated flows file.
2025-11-30 Added a BOM link and updated price changes. Added a DrInfaredHeaterRemoteThermostat.csv for compatibility. ReadME was also read through and updated.
    [DrInfraredHeaterRemoteThermostat_BOM.csv, DrInfraredHeaterRemoteThermostat_BOM.xlsx]
2025-12-08 Added updated Flows.json and Node-REDFlowsExplained.pdf for v2.1.0
2026-03-28 Apply fix for heater state logging to resolve #1 and Node-REDFlowsExplained updated.
2026-04-26 New image, new Flows.json file, and Updated ReadMe.
2026-08-30 PCB Design readme details about halfway done. Images and pdf files added related to PCB design documentation.
2026-08-30 Main readme updated to reference new PCB Design readme.
2026-08-30 Added "Printed Circuit Board Design" to main ReadMe Navigation section.
2026-08-31 MNore PCBDesign documentation.
2026-08-31 PCB Design grammar fixed.
